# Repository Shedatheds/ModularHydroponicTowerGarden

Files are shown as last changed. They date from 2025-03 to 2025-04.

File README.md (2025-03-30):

# ModularHydroponicTowerGarden
A modular 3D-printable hydroponic tower garden with Arduino compatible water pump controller.

[Get one or two on Tindie!](https://www.tindie.com/products/19512/)

**3DPrint** folder contains the STEP-files to print tower parts.

**Arduino** folder contains the source code and compiled binaries for the water pump controller written in Arduino IDE 1.8.12.

**GUI** folder contains the C# source code and compiled Windows binary for an external computer written in Visual Studio 2019.

**PCB** folder contains everything to manufacture and assemble the hardware. You can buy it on [Tindie.](https://www.tindie.com/products/19512/)

## Command Line Interface (CLI)

The water pump controller can be interfaced with the Arduino Serial Monitor, or any other Serial Monitor application, regardless of OS platform, to change its settings via text-based commands. The current GUI works on Windows OS only.

By default the Serial Monitor shows regular status updates:

```
...
-----------STATUS-----------
Service mode : disabled
  Water pump : on @ 80%
       Timer : 00:04:46 left
Temperatures
    external : 0.0°C
    internal : 0.0°C
----------------------------

-----------STATUS-----------
Service mode : disabled
  Water pump : on @ 80%
       Timer : 00:04:45 left
Temperatures
    external : 0.0°C
    internal : 0.0°C
----------------------------

-----------STATUS-----------
Service mode : disabled
  Water pump : on @ 80%
       Timer : 00:04:44 left
Temperatures
    external : 0.0°C
    internal : 0.0°C
----------------------------
...
```

To turn off regular status update display send this command:

```
status=0
```

The Serial Monitor reacts the following way to user inputs:

```
Input: status=0
Command: status
Value: 0
Result: regular status updates disabled.
```

With the command "help" a complete description is printed to the Serial Monitor on the available commands:

```
----------------------------------HELP---------------------------------
         help : print this description.
      restart : restart controller.
         info : print controller information.
servicemode=X : set service mode,
                X=0: disabled (default),
                X=1: enabled.
     status=X : print regular status updates,
                X=0: disabled,
                X=1: enabled (default).
  pumpspeed=X : set water pump speed in percents,
                X=0...100 [%].
     ontime=X : set water pump on-time in minutes,
                X=0...71582 [min],
                when set to 0 the water pump is permanently turned off.
    offtime=X : set water pump off-time in minutes,
                X=0...71582 [min],
                when set to 0 the water pump is permanently turned on.
tempsensors=X : set temperature sensor configuration,
                X=0: none (default),
                X=1: external,
                X=2: internal,
                X=3: both external and internal.
   tempunit=X : set temperature unit,
                X=1: Celsius (default),
                X=2: Fahrenheit,
                X=4: Kelvin.
    ntcbeta=X : set temperature sensor beta value in Kelvin,
                X=3950 [K] by default.
    pwmfreq=X : set water pump driver PWM frequency in Hertz,
                X=490 [Hz] by default.

Note: settings are automatically saved to the internal EEPROM.
-----------------------------------------------------------------------
```

To display controller information send the "info" command:

```
--------------------INFO---------------------
        AVR signature : 1E 95 0F (ATmega328P)
     Hardware version : V1.01
        Hardware date : 2019.11.18 18:07:36
        Assembly date : 2020.03.09 13:20:28
        Firmware date : 2021.04.20 14:02:43
         Service mode : disabled
     Water pump state : off
   Water pump on-time : 5 minute(s)
  Water pump off-time : 60 minute(s)
Temperature sensor(s) : external and internal
     Temperature unit : Celsius
       NTC beta value : 3950 K
        PWM frequency : 490 Hz
---------------------------------------------
```

## Pictures

MHTG empty

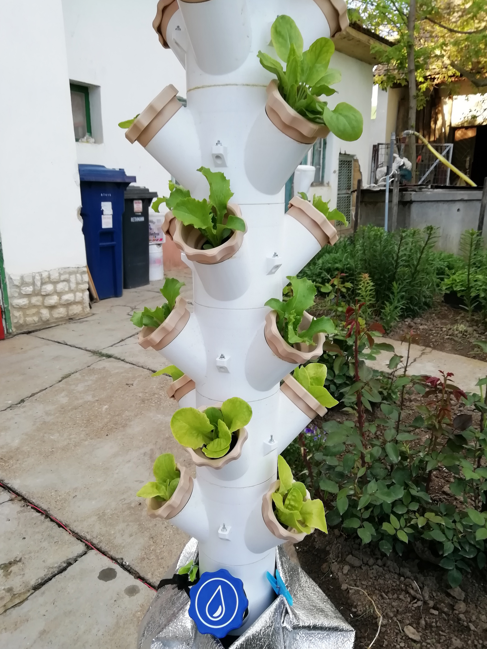
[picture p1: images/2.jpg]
MHTG seedlings


MHTG halfway through

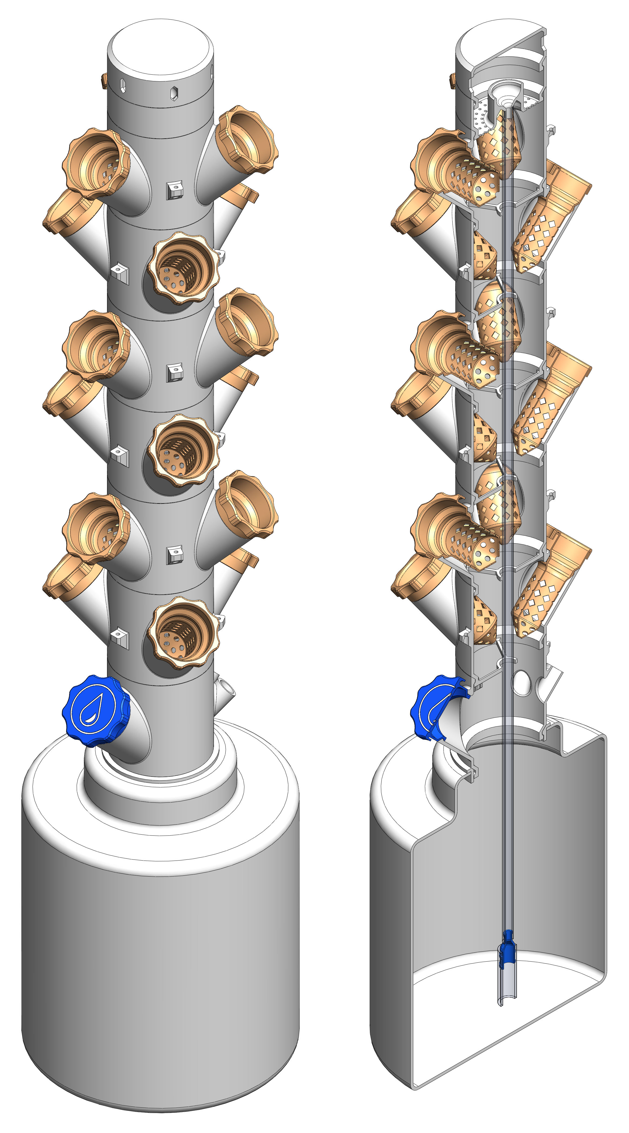
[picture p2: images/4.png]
MHTG CAD drawing


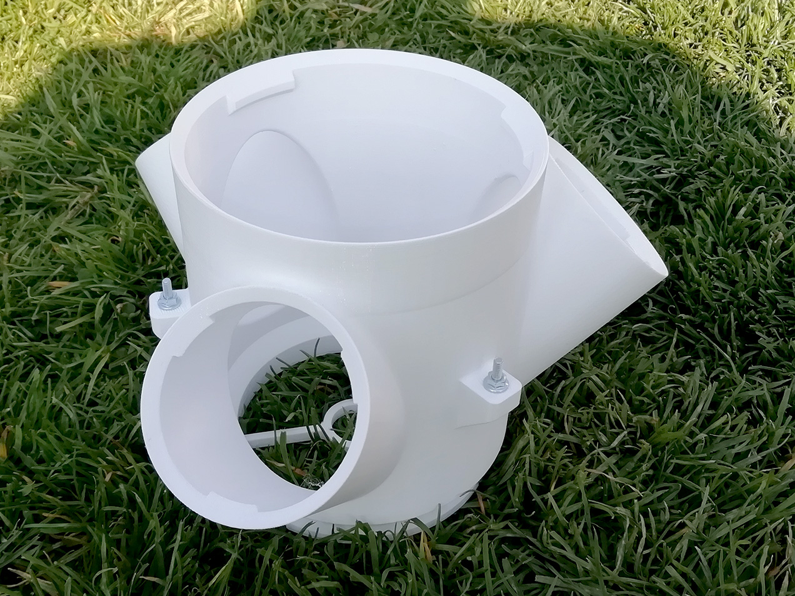
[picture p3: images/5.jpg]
MHTG planting module


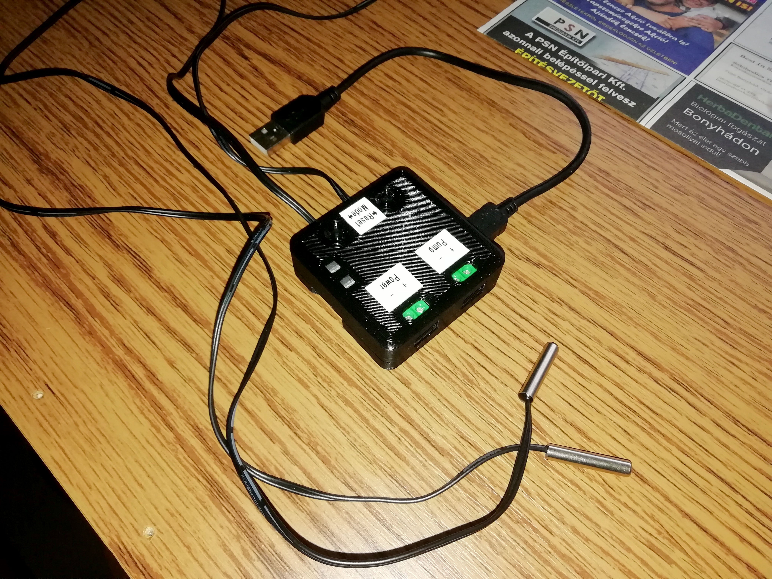
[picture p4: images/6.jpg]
V1.02 water pump controller


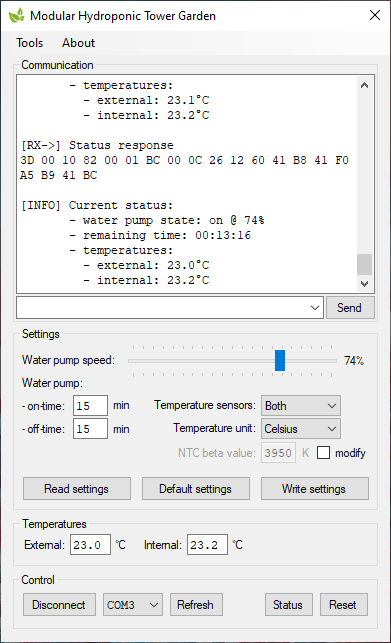
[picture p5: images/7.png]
MHTG GUI 01


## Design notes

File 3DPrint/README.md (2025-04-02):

Features

    Modular structure, easily scalable, put modules together, twist & lock, done
    Module adapter to be glued into water tank's lid
    Filling module with cap
    1/2/3/4/5-way planting modules (hollow version recommended)
    Spacer modules (optional)
    Internal/external water dispenser modules
    Cone module for external water circulation systems
    Lid
    Custom net pot for Jiffy-7 41 mm grow medium (dry pressed dimensions: diameter 37 mm, thickness: 7.5 mm)
    Custom net pot with 48 mm internal diameter for other grow medium (rockwool + clay pebbles)
    M3 screw points on planting modules for plant tagging and general fixture purposes
    Any kind of water pump works with this system
    2" net pots fit into planting ports

Dimensions

    Outer diameter of planting modules: 115 mm
    Inner diameter of planting modules: 107 mm
    Planting module height: 120 mm
    Spacer module heights: 40/80/120 mm
    Wall thickness: 4 mm
    Clear inner diameter of pot trays: 53.5 mm
    Outer diameter of pot trays: 65 mm
    Compatible silicone hose: ID 10 mm fixed, OD 18 mm (max),
    Temperature sensor mounts in the filling module (10k thermistor): 5 mm cylindrical shell diameter.

Printing recommendations

    0.3 mm layer
    3 wall count (0.4 mm nozzle = 1.2 mm)
    15% infill
    40 mm/s or more printing speed
    no support
    210x210 mm printing area required
    Use wide brims whenever the surface touching the bed is small (filling module, hollow planting modules)

    With above settings a 3-way planting module takes 12 hours to print.

Watering schedule

    Last year I started with 30 minutes on and 30 minutes off. Works well.
    My current schedule is 5 minutes on and 20 minutes off.
    You can further shorten the on-time and lengthen the off-time if power saving is a requirement. Let the roots of the plants be completely wet (should take a few minutes at least) and start the water pump again when they start to dry out (up to 1 hour).

    If you don't have a timer then continuous water circulation is appropriate.

FAQ

    What parts do I print for a very basic setup (1 module) on a 5 gallon bucket?

    Original bucket lid or a lid from the Remixes section.
    Module_Adapter_With_Tabs.STL
    3-Way_Planting_Module_Hollow.STL
    Standard_Pot_02.STL
    Dispenser_Module_Internal.STL
    Lid_Without_Holes.STL

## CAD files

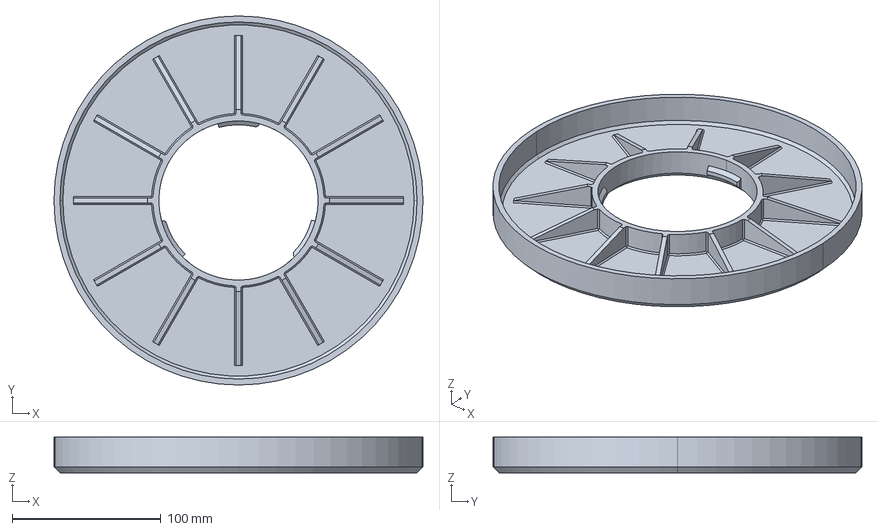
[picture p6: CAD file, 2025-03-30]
3DPrint/STEP/IKEA_Muskot_Pot_7_12_Adapter_ID=240mm_Full.STEP
248.0 x 248.0 x 24.0 mm

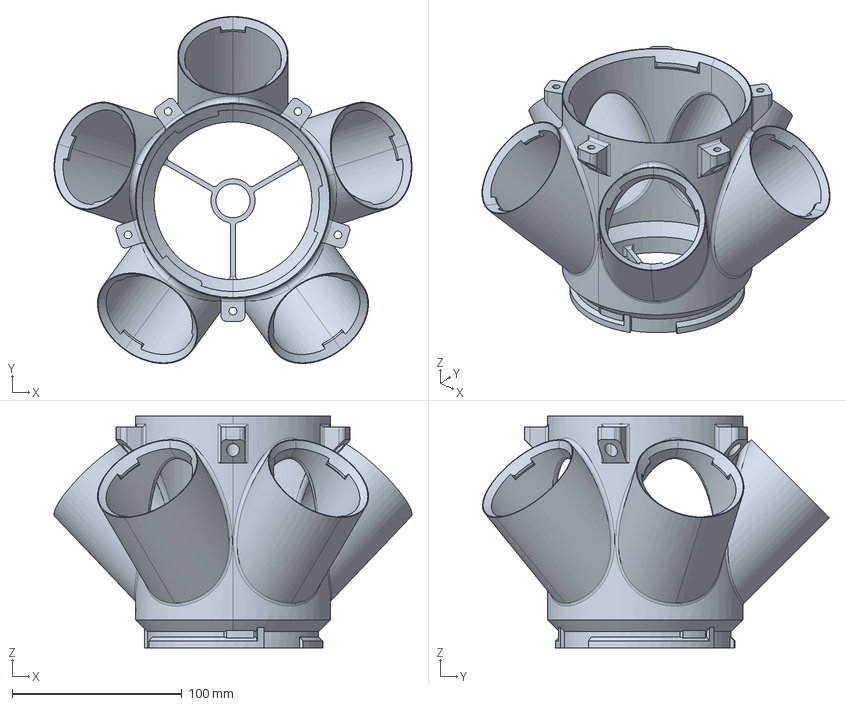
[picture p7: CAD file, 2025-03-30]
3DPrint/STEP/5-Way_Planting_Module_Hollow.STEP
210.8 x 204.4 x 136.5 mm

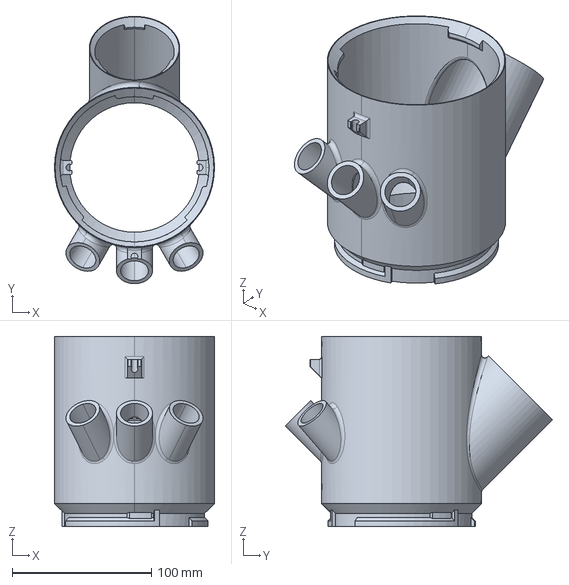
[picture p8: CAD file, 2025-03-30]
3DPrint/STEP/Filling_Module.STEP
115.0 x 192.0 x 136.5 mm

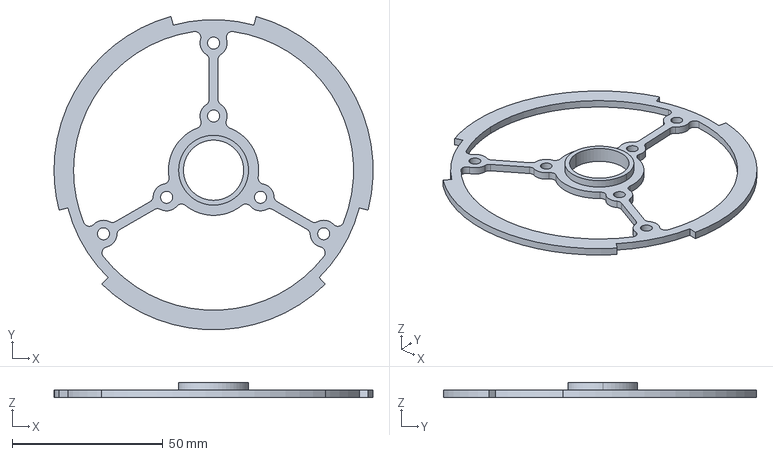
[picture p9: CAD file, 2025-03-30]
3DPrint/STEP/Filtration_Mesh_Holder_02.STEP
105.9 x 104.0 x 5.00 mm

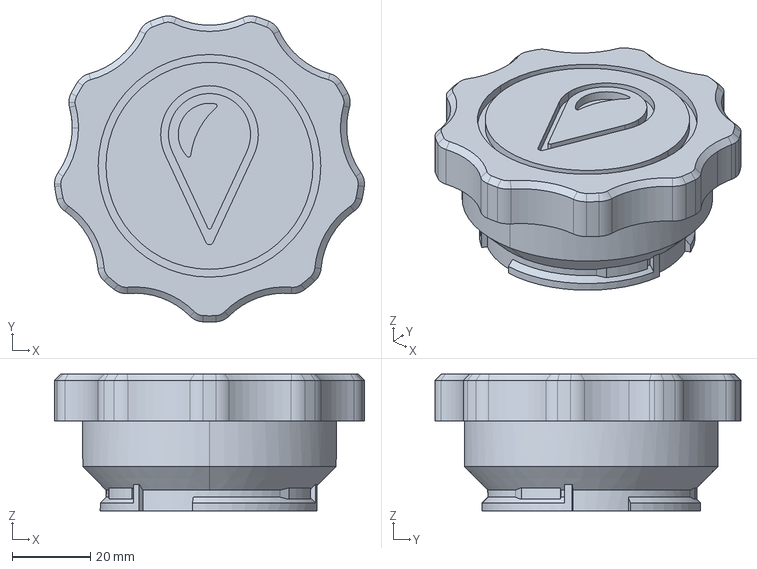
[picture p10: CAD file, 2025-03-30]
3DPrint/STEP/Filling_Cap.STEP
79.4 x 78.3 x 35.0 mm

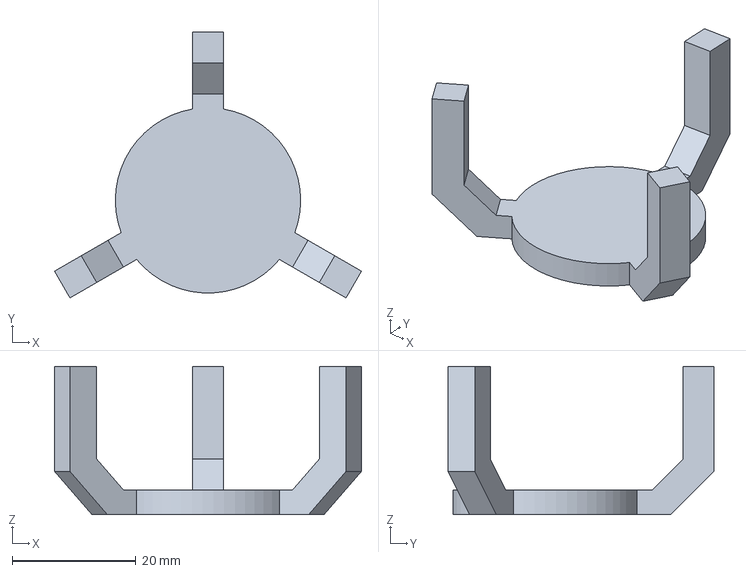
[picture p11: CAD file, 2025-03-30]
3DPrint/STEP/Stream_Breaker.STEP
49.7 x 43.0 x 24.0 mm

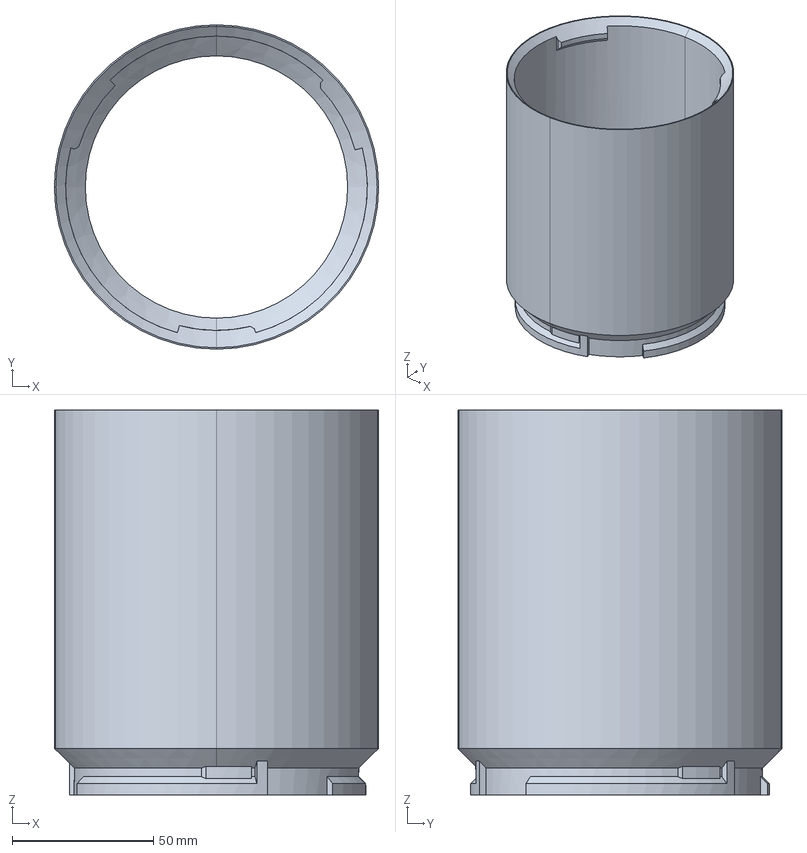
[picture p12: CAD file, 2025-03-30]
3DPrint/STEP/Module_Spacer_120mm.STEP
115.0 x 115.0 x 136.5 mm

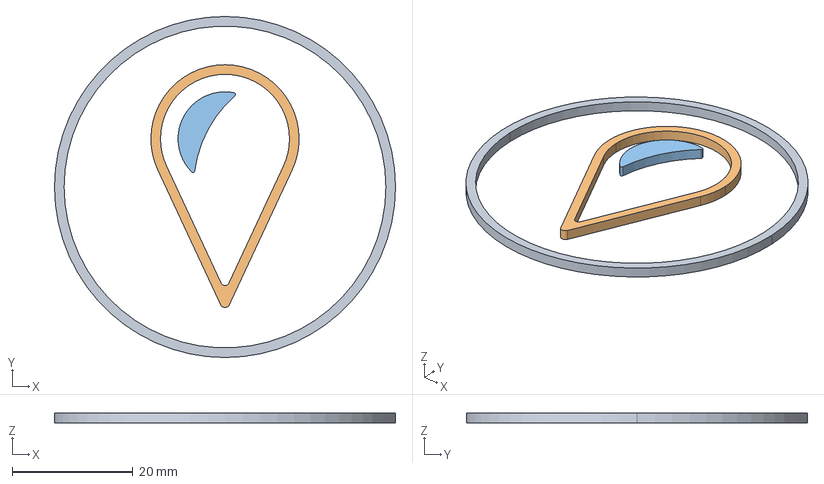
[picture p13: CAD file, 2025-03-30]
3DPrint/STEP/Filling_Cap_Symbol.STEP
56.6 x 56.6 x 1.70 mm

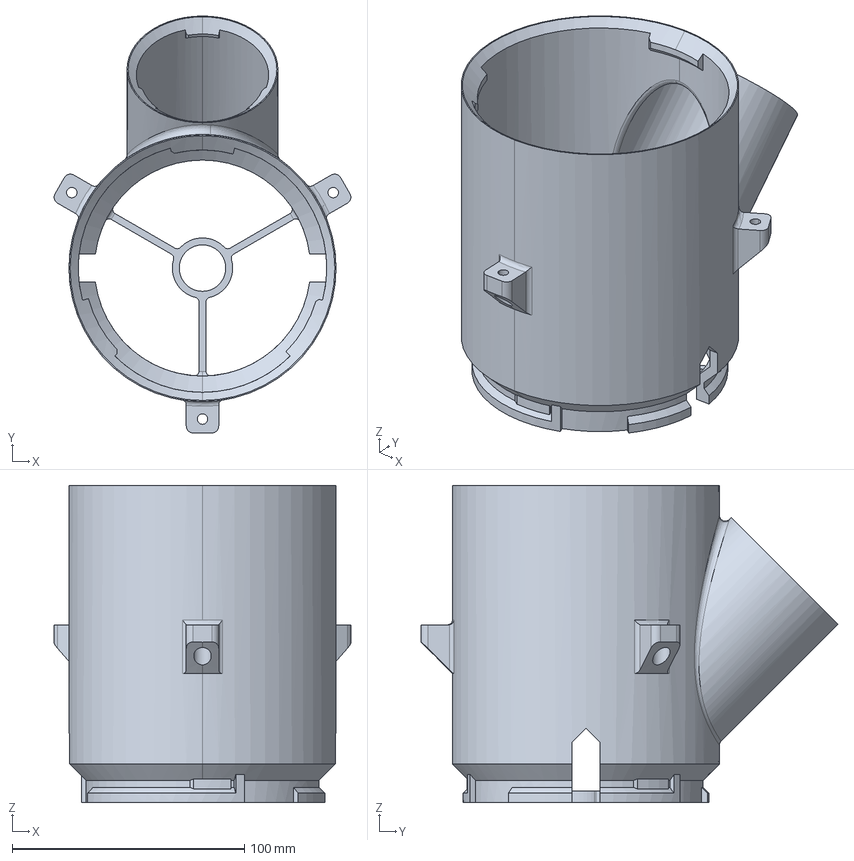
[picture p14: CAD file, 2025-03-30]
3DPrint/STEP/1-Way_Planting_Module_Hollow_Cut.STEP
127.8 x 179.5 x 136.5 mm

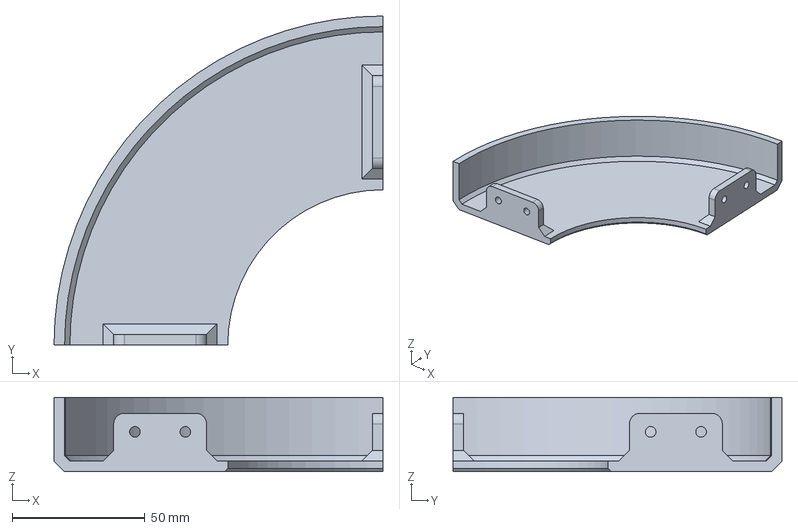
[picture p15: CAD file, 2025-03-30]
3DPrint/STEP/IKEA_Muskot_Pot_7_12_Adapter_ID=240mm.STEP
124.0 x 124.0 x 28.0 mm

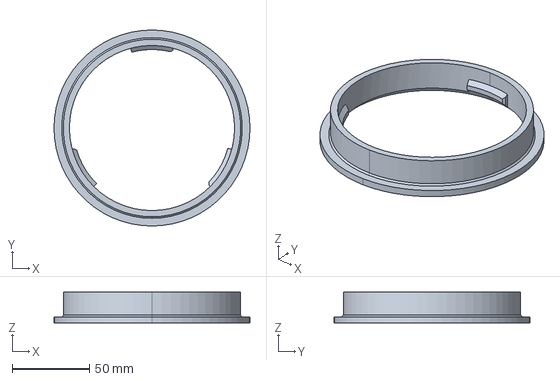
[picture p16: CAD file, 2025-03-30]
3DPrint/STEP/Module_Adapter.STEP
127.0 x 127.0 x 20.0 mm

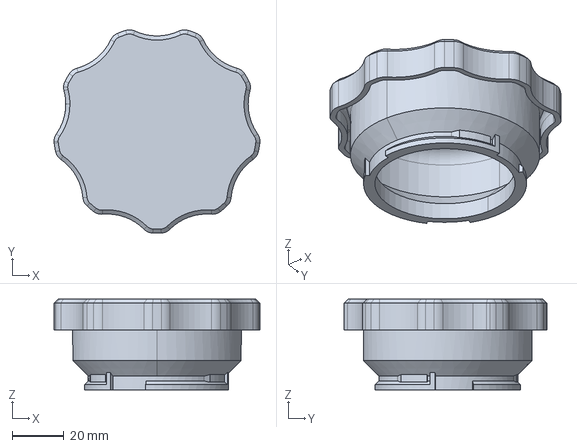
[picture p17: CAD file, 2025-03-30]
3DPrint/STEP/Blank_Cap.STEP
79.4 x 78.3 x 35.0 mm

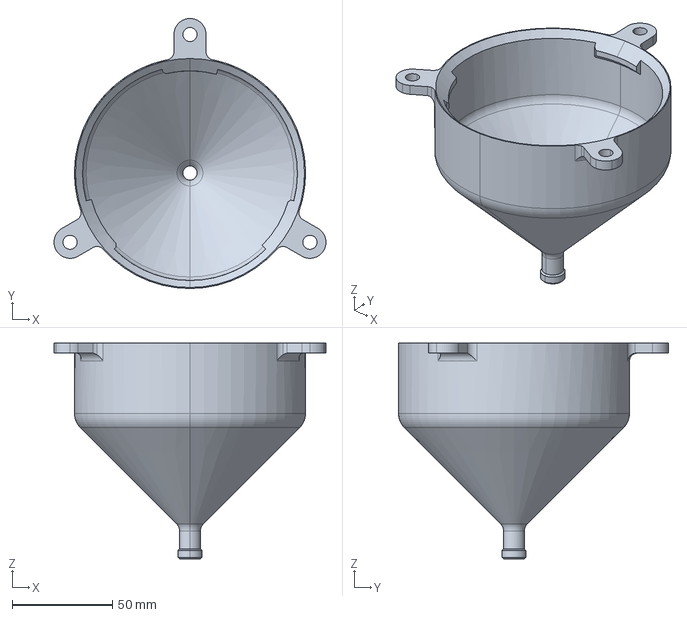
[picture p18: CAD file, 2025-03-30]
3DPrint/STEP/Cone_Module.STEP
135.4 x 134.4 x 107.5 mm

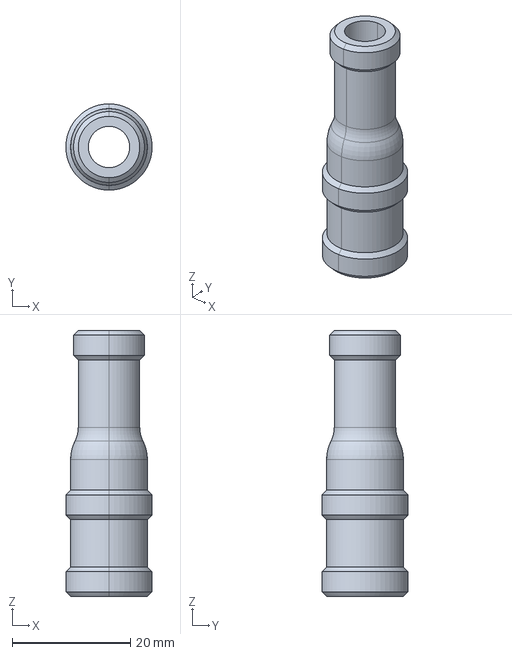
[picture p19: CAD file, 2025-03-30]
3DPrint/STEP/Waterpump_Hose_Adapter_02.STEP
14.6 x 14.6 x 45.0 mm

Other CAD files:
3DPrint/STEP/Dispenser_Module_External_02.STEP
3DPrint/STEP/Lid_Without_Holes.STEP
3DPrint/STEP/Jiffy-7_41_Pot_02.STEP
3DPrint/STEP/5-Way_Planting_Module_Hollow_Without_M3.STEP
3DPrint/STEP/1-Way_Planting_Module.STEP
3DPrint/STEP/1-Way_Planting_Module_Hollow.STEP
3DPrint/STEP/1-Way_Planting_Module_Hollow_Without_M3.STEP
3DPrint/STEP/2-Way_Planting_Module.STEP
3DPrint/STEP/2-Way_Planting_Module_Hollow.STEP
3DPrint/STEP/2-Way_Planting_Module_Hollow_Without_M3.STEP
3DPrint/STEP/3-Way_Planting_Module.STEP
3DPrint/STEP/3-Way_Planting_Module_Hollow.STEP
3DPrint/STEP/3-Way_Planting_Module_Hollow_Without_M3.STEP
3DPrint/STEP/4-Way_Planting_Module_Hollow.STEP
3DPrint/STEP/4-Way_Planting_Module_Hollow_Without_M3.STEP
3DPrint/STEP/Dispenser_Module_External_01.STEP
3DPrint/STEP/Dispenser_Module_External_01_Without_Holes.STEP
3DPrint/STEP/Dispenser_Module_Internal.STEP
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
